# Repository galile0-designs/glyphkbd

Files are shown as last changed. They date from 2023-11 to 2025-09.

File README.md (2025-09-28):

# glyphkbd
**5x13 ortholinear plus TKL nav and arrow clusters**  - Key layout inspired by [drFaustroll's m65](https://mlego.elena.space/m65/) as well as [Stucco](https://www.reddit.com/r/CustomKeyboards/comments/10k8k6w/custom_ortho_tkl_done_stucco1510/).

# v2
glyphkbd_v2 uses a custom PCB with integrated STM32F072 microcontroller using [QMK firmware](https://github.com/qmk/qmk_firmware) [(here)](https://github.com/qmk/qmk_firmware/pull/23131), with [VIA](https://github.com/the-via) use enabled. 3D printed top mount case, [UDB](https://github.com/Unified-Daughterboard/Unified-Daughterboard.github.io) daughterboard for external USB-C connection.

DSC_0071_crop




# License
glyphkbd is licensed under Creative Commons Attribution-NonCommercial-ShareAlike 4.0

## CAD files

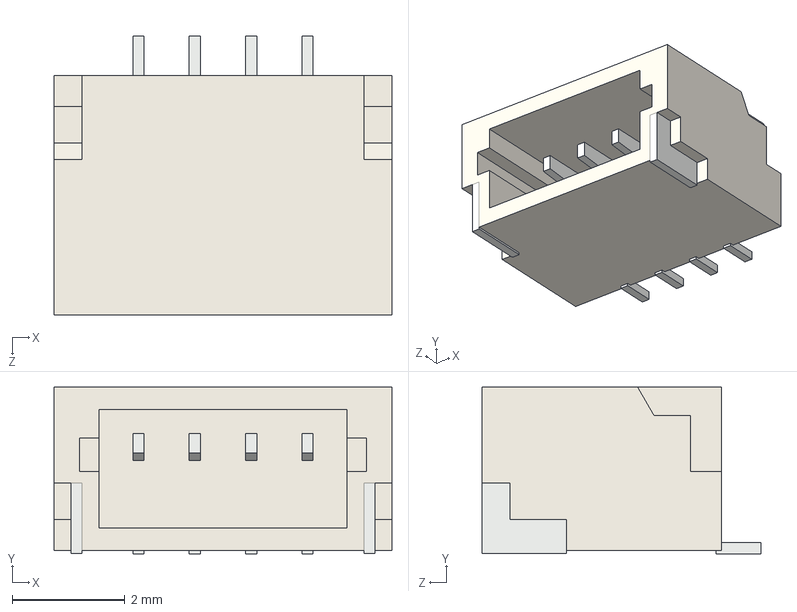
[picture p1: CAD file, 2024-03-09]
v2/PCB/JST SM04B-SRSS-TB.STEP
6.00 x 2.96 x 4.95 mm

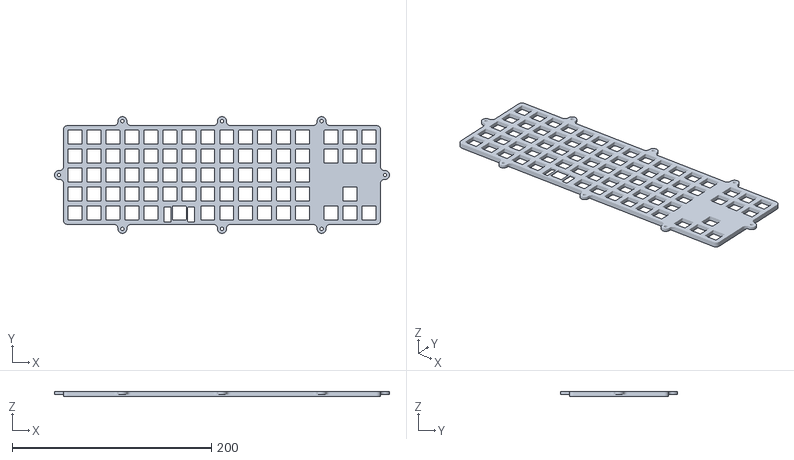
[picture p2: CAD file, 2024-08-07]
v2/printed parts/plate.stl
336.3 x 117.2 x 5.00

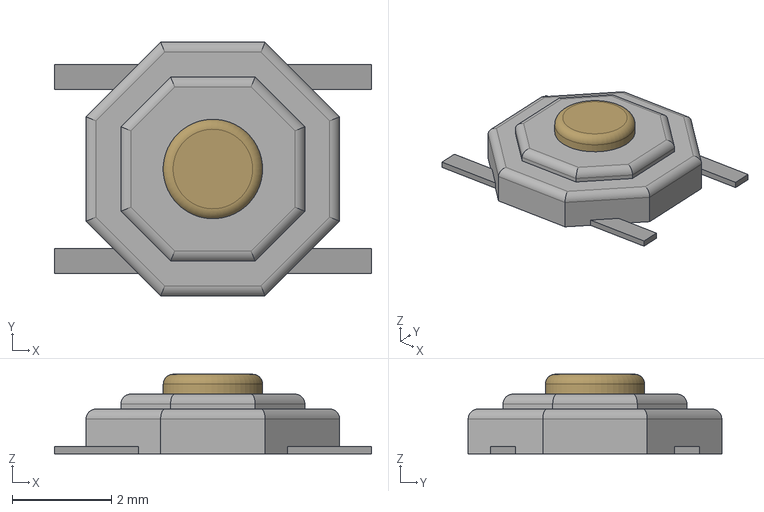
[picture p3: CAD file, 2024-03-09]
v2/PCB/TS-1187A-B-A-B.step
6.38 x 5.10 x 1.60 mm

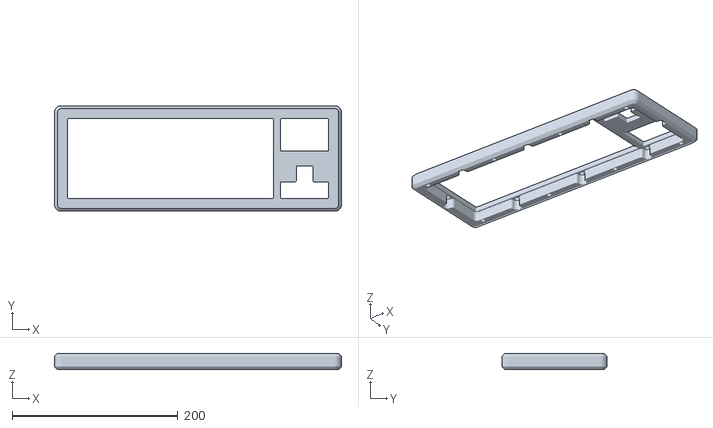
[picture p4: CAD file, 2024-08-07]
v2/printed parts/case.stl
346.3 x 127.2 x 19.5

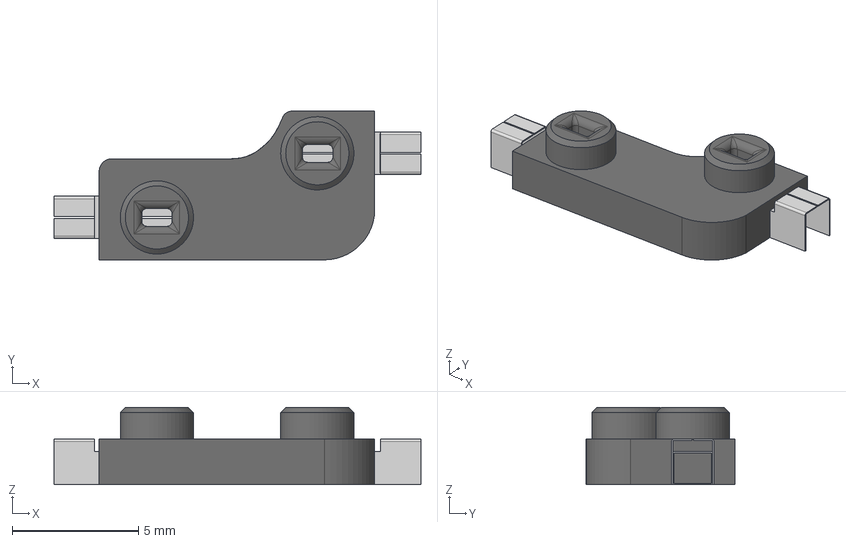
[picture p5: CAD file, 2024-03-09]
v2/PCB/Kailh-CherryMX-Socket.step
14.5 x 5.89 x 3.05 mm

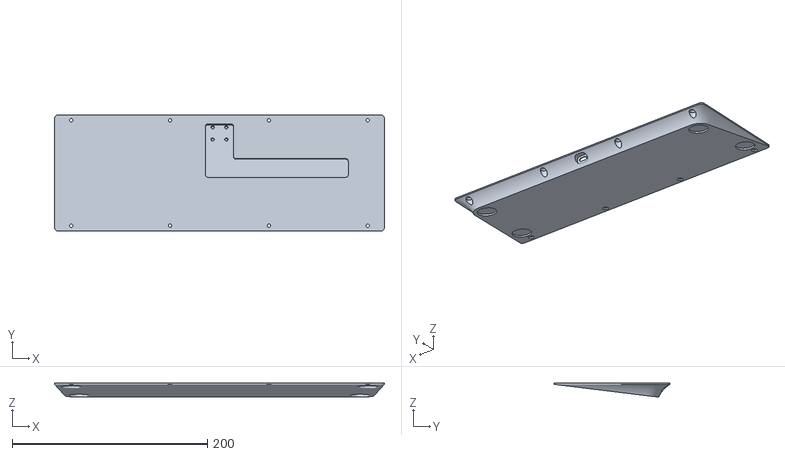
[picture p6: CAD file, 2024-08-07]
v2/printed parts/bottom.stl
338.3 x 119.2 x 14.7

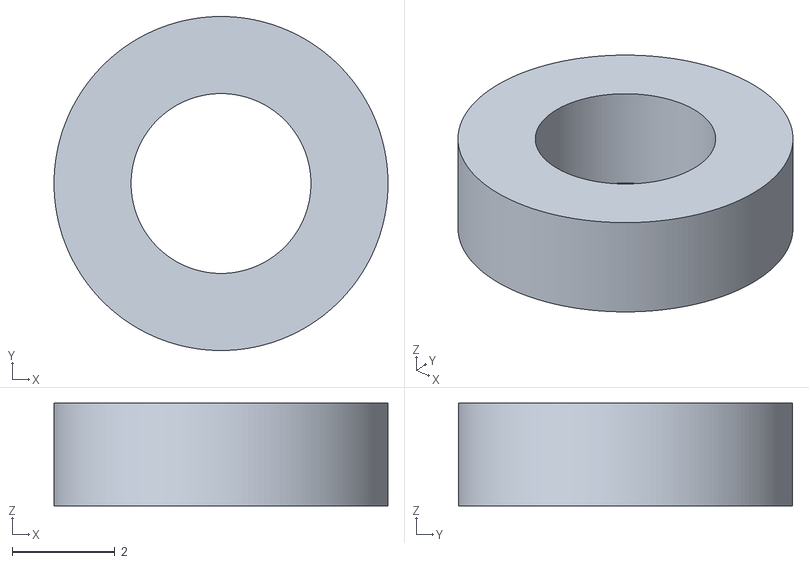
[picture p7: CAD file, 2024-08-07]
v2/printed parts/6x2_topmount_washer.stl
6.50 x 6.50 x 2.00

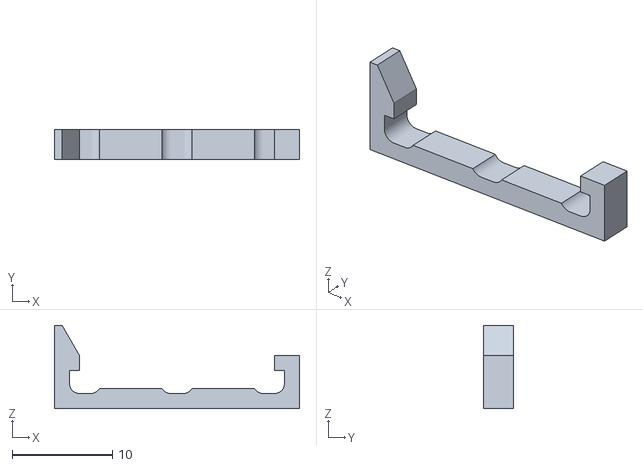
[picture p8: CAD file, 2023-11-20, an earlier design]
v1.2/printed parts/Pico Clip.stl
24.5 x 3.00 x 8.30

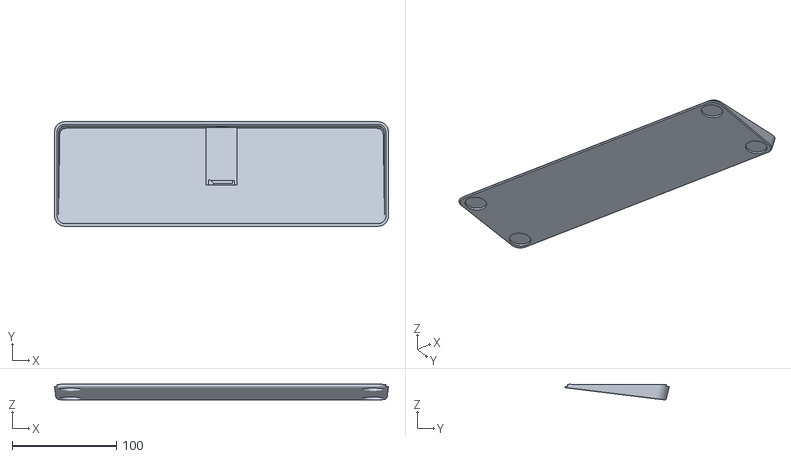
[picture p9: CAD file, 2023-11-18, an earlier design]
v1.2/printed parts/Foot.stl
320.0 x 100.2 x 15.3

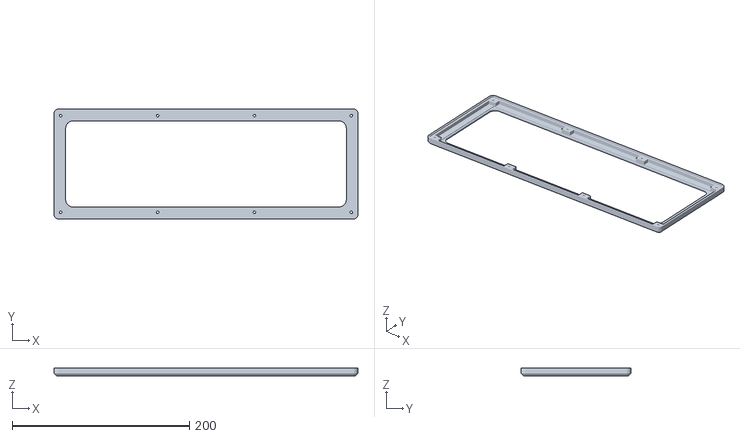
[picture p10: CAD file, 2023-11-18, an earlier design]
v1.2/printed parts/Bottom Case.stl
343.3 x 124.2 x 9.25

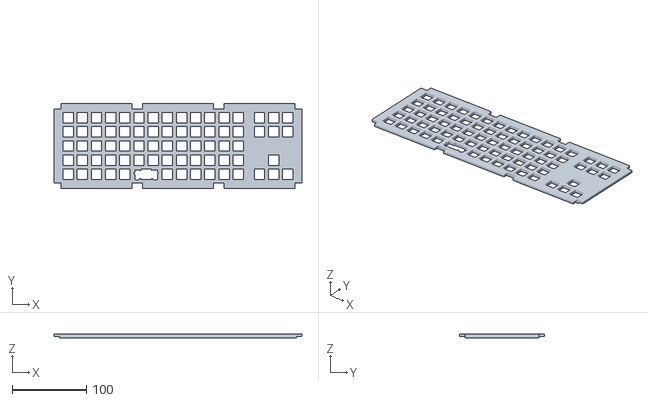
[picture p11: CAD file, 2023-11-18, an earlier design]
v1.2/printed parts/Plate.stl
333.3 x 114.2 x 5.00

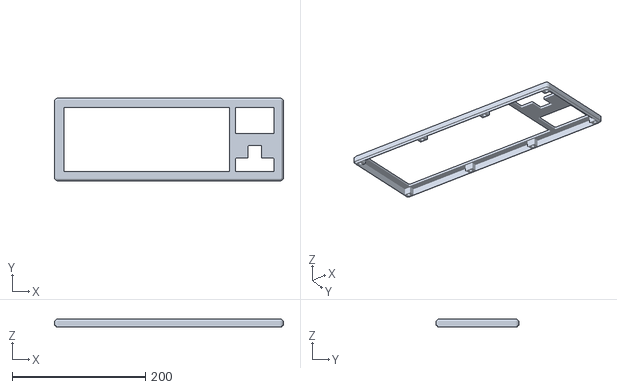
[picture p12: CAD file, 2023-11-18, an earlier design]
v1.2/printed parts/Top Case.stl
343.3 x 124.2 x 11.5

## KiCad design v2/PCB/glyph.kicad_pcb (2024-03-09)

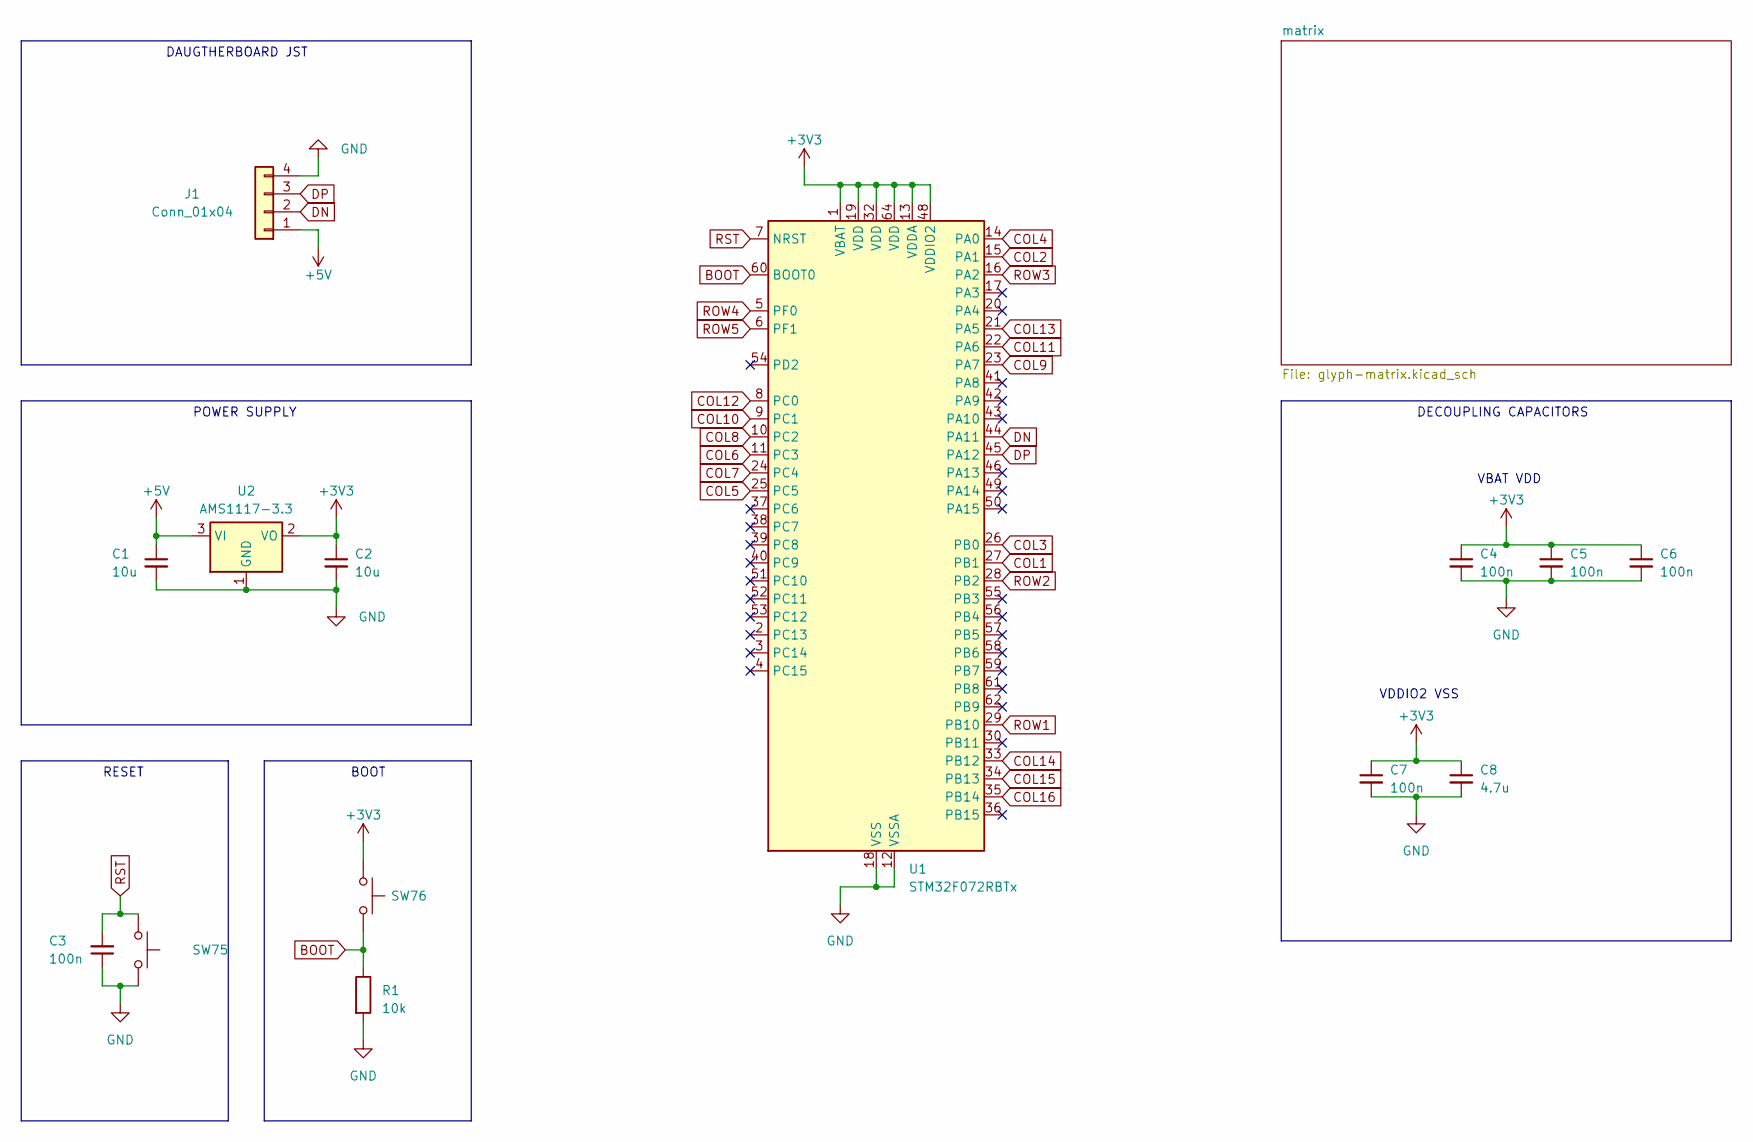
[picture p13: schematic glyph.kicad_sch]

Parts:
C1, C2: 10u; C_0402_1005Metric; LCSC C15525
C3, C4, C5, C6, C7: 100n; C_0402_1005Metric; LCSC C1525
C8: 4.7u; C_0402_1005Metric; LCSC C23733
J1: Conn_01x04; UDB_labeled_JST_SH_SM04B-SRSS-TB_1x04-1MP_P1.00mm_Horizontal; LCSC C160404
R1: 10k; R_0603_1608Metric; LCSC C25804
SW75, SW76: SW_Push; SW_Push_1P1T_XKB_TS-1187A; LCSC C318884
U1: STM32F072RBTx; LQFP-64_10x10mm_P0.5mm; LCSC C46046
U2: AMS1117-3.3; SOT-223-3_TabPin2; LCSC C6186

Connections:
+3V3: C2.1, C4.1, C5.1, C6.1, C7.1, C8.1, SW76.1, U1.1 (VBAT), U1.13 (VDDA), U1.19 (VDD), U1.32 (VDD), U1.48 (VDDIO2), U1.64 (VDD), U2.2 (VO); also elsewhere on the board
+5V: C1.1, J1.1, U2.3 (VI)
BOOT: R1.1, SW76.2, U1.60 (BOOT0); also elsewhere on the board
COL1: U1.27 (PB1); also elsewhere on the board
COL2: U1.15 (PA1); also elsewhere on the board
COL3: U1.26 (PB0); also elsewhere on the board
COL4: U1.14 (PA0); also elsewhere on the board
COL5: U1.25 (PC5); also elsewhere on the board
COL6: U1.11 (PC3); also elsewhere on the board
COL7: U1.24 (PC4); also elsewhere on the board
COL8: U1.10 (PC2); also elsewhere on the board
COL9: U1.23 (PA7); also elsewhere on the board
COL10: U1.9 (PC1); also elsewhere on the board
COL11: U1.22 (PA6); also elsewhere on the board
COL12: U1.8 (PC0); also elsewhere on the board
COL13: U1.21 (PA5); also elsewhere on the board
COL14: U1.33 (PB12); also elsewhere on the board
COL15: U1.34 (PB13); also elsewhere on the board
COL16: U1.35 (PB14); also elsewhere on the board
DN: J1.2, U1.44 (PA11)
DP: J1.3, U1.45 (PA12)
GND: C1.2, C2.2, C3.1, C4.2, C5.2, C6.2, C7.2, C8.2, J1.4, J1.MP, R1.2, SW75.1, U1.12 (VSSA), U1.18 (VSS), U1.31 (VSS), U1.47 (VSS), U1.63 (VSS), U2.1 (GND); also elsewhere on the board
ROW1: U1.29 (PB10); also elsewhere on the board
ROW2: U1.28 (PB2); also elsewhere on the board
ROW3: U1.16 (PA2); also elsewhere on the board
ROW4: U1.5 (PF0); also elsewhere on the board
ROW5: U1.6 (PF1); also elsewhere on the board
RST: C3.2, SW75.2, U1.7 (NRST); also elsewhere on the board

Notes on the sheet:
DAUGTHERBOARD JST
BOOT
VBAT VDD
RESET
DECOUPLING CAPACITORS
POWER SUPPLY
VDDIO2 VSS

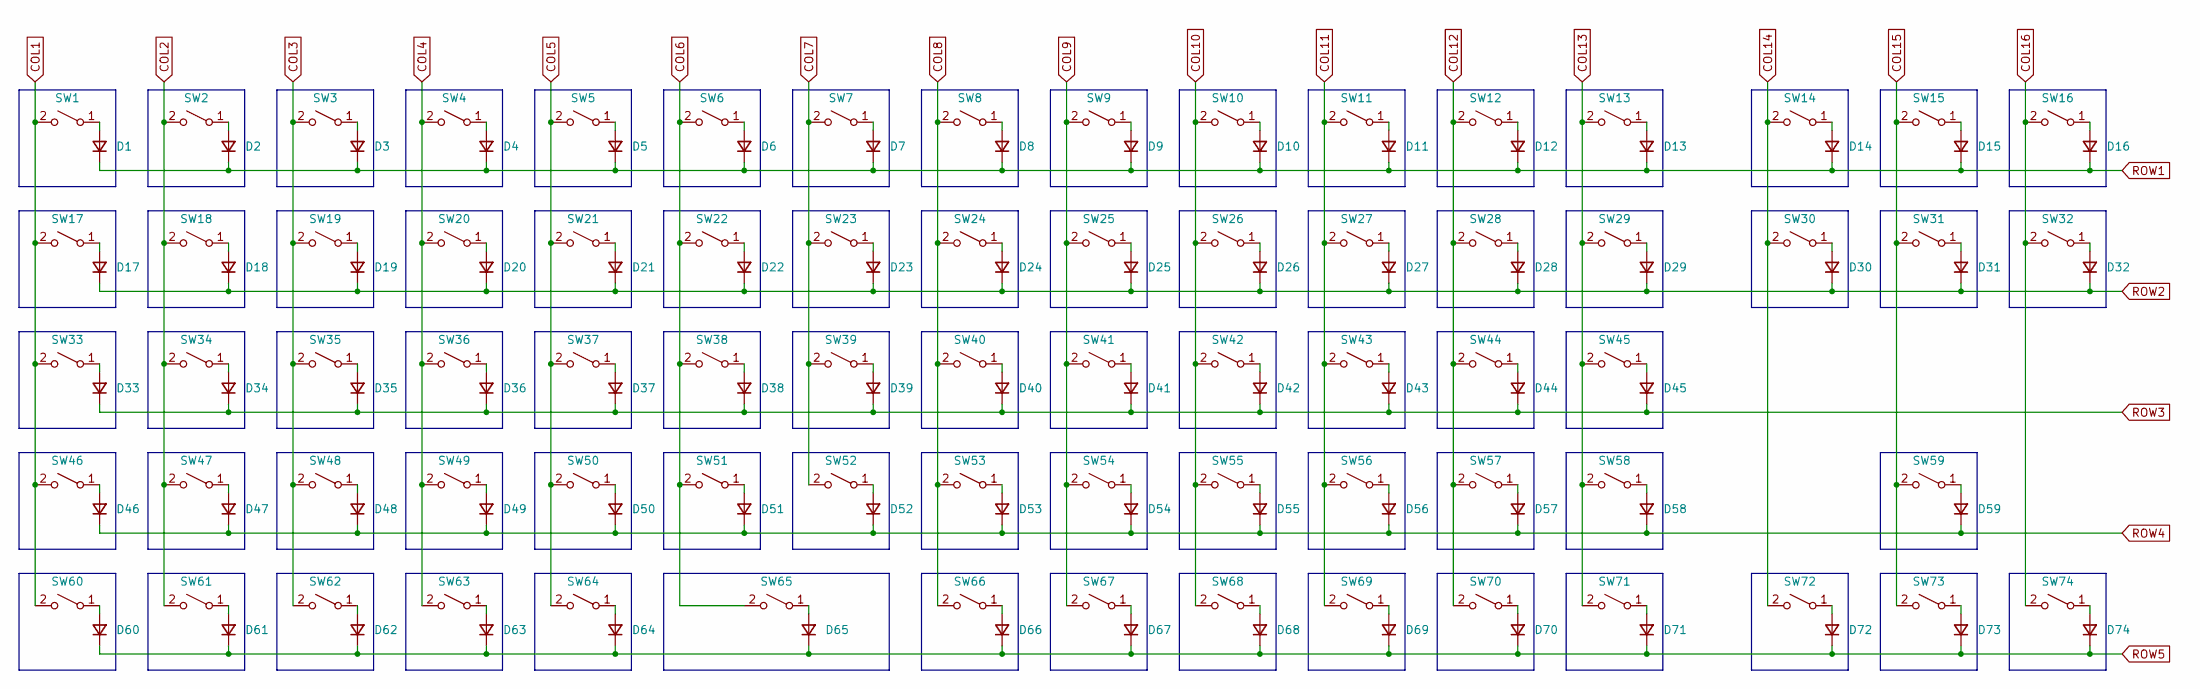
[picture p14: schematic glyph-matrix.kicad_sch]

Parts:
D1, D2, D3, D4, D5, D6, D7, D8, D9, D10, D11, D12, D13, D14, D15, D16, D17, D18, D19, D20, D21, D22, D23, D24, D25, D26, D27, D28, D29, D30, D31, D32, D33, D34, D35, D36, D37, D38, D39, D40, D41, D42, D43, D44, D45, D46, D47, D48, D49, D50, D51, D52, D53, D54, D55, D56, D57, D58, D59, D60, D61, D62, D63, D64, D65, D66, D67, D68, D69, D70, D71, D72, D73, D74: D; D_SOD-123; LCSC C81598
SW1, SW2, SW3, SW4, SW5, SW6, SW7, SW8, SW9, SW10, SW11, SW12, SW13, SW14, SW15, SW16, SW17, SW18, SW19, SW20, SW21, SW22, SW23, SW24, SW25, SW26, SW27, SW28, SW29, SW30, SW31, SW32, SW33, SW34, SW35, SW36, SW37, SW38, SW39, SW40, SW41, SW42, SW43, SW44, SW45, SW46, SW47, SW48, SW49, SW50, SW51, SW52, SW53, SW54, SW55, SW56, SW57, SW58, SW59, SW60, SW61, SW62, SW63, SW64, SW66, SW67, SW68, SW69, SW70, SW71, SW72, SW73, SW74: SW_SPST; CherryMX_Hotswap-Solderable_1u; LCSC C5156480
SW65: SW_SPST; CherryMX_Hotswap-Solderable_2u; LCSC C5156480

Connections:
COL1: SW1.2 (B), SW17.2 (B), SW33.2 (B), SW46.2 (B), SW60.2 (B); also elsewhere on the board
COL2: SW2.2 (B), SW18.2 (B), SW34.2 (B), SW47.2 (B), SW61.2 (B); also elsewhere on the board
COL3: SW3.2 (B), SW19.2 (B), SW35.2 (B), SW48.2 (B), SW62.2 (B); also elsewhere on the board
COL4: SW4.2 (B), SW20.2 (B), SW36.2 (B), SW49.2 (B), SW63.2 (B); also elsewhere on the board
COL5: SW5.2 (B), SW21.2 (B), SW37.2 (B), SW50.2 (B), SW64.2 (B); also elsewhere on the board
COL6: SW6.2 (B), SW22.2 (B), SW38.2 (B), SW51.2 (B), SW65.2 (B); also elsewhere on the board
COL7: SW7.2 (B), SW23.2 (B), SW39.2 (B), SW52.2 (B); also elsewhere on the board
COL8: SW8.2 (B), SW24.2 (B), SW40.2 (B), SW53.2 (B), SW66.2 (B); also elsewhere on the board
COL9: SW9.2 (B), SW25.2 (B), SW41.2 (B), SW54.2 (B), SW67.2 (B); also elsewhere on the board
COL10: SW10.2 (B), SW26.2 (B), SW42.2 (B), SW55.2 (B), SW68.2 (B); also elsewhere on the board
COL11: SW11.2 (B), SW27.2 (B), SW43.2 (B), SW56.2 (B), SW69.2 (B); also elsewhere on the board
COL12: SW12.2 (B), SW28.2 (B), SW44.2 (B), SW57.2 (B), SW70.2 (B); also elsewhere on the board
COL13: SW13.2 (B), SW29.2 (B), SW45.2 (B), SW58.2 (B), SW71.2 (B); also elsewhere on the board
COL14: SW14.2 (B), SW30.2 (B), SW72.2 (B); also elsewhere on the board
COL15: SW15.2 (B), SW31.2 (B), SW59.2 (B), SW73.2 (B); also elsewhere on the board
COL16: SW16.2 (B), SW32.2 (B), SW74.2 (B); also elsewhere on the board
unnamed: D1.2 (A), SW1.1 (A)
unnamed: D2.2 (A), SW2.1 (A)
unnamed: D3.2 (A), SW3.1 (A)
unnamed: D4.2 (A), SW4.1 (A)
unnamed: D5.2 (A), SW5.1 (A)
unnamed: D6.2 (A), SW6.1 (A)
unnamed: D7.2 (A), SW7.1 (A)
unnamed: D8.2 (A), SW8.1 (A)
unnamed: D9.2 (A), SW9.1 (A)
unnamed: D10.2 (A), SW10.1 (A)
unnamed: D11.2 (A), SW11.1 (A)
unnamed: D12.2 (A), SW12.1 (A)
unnamed: D13.2 (A), SW13.1 (A)
unnamed: D14.2 (A), SW14.1 (A)
unnamed: D15.2 (A), SW15.1 (A)
unnamed: D16.2 (A), SW16.1 (A)
unnamed: D17.2 (A), SW17.1 (A)
unnamed: D18.2 (A), SW18.1 (A)
unnamed: D19.2 (A), SW19.1 (A)
unnamed: D20.2 (A), SW20.1 (A)
unnamed: D21.2 (A), SW21.1 (A)
unnamed: D22.2 (A), SW22.1 (A)
unnamed: D23.2 (A), SW23.1 (A)
unnamed: D24.2 (A), SW24.1 (A)
unnamed: D25.2 (A), SW25.1 (A)
unnamed: D26.2 (A), SW26.1 (A)
unnamed: D27.2 (A), SW27.1 (A)
unnamed: D28.2 (A), SW28.1 (A)
unnamed: D29.2 (A), SW29.1 (A)
unnamed: D30.2 (A), SW30.1 (A)
unnamed: D31.2 (A), SW31.1 (A)
unnamed: D32.2 (A), SW32.1 (A)
unnamed: D33.2 (A), SW33.1 (A)
unnamed: D34.2 (A), SW34.1 (A)
unnamed: D35.2 (A), SW35.1 (A)
unnamed: D36.2 (A), SW36.1 (A)
unnamed: D37.2 (A), SW37.1 (A)
unnamed: D38.2 (A), SW38.1 (A)
unnamed: D39.2 (A), SW39.1 (A)
unnamed: D40.2 (A), SW40.1 (A)
unnamed: D41.2 (A), SW41.1 (A)
unnamed: D42.2 (A), SW42.1 (A)
unnamed: D43.2 (A), SW43.1 (A)
unnamed: D44.2 (A), SW44.1 (A)
unnamed: D45.2 (A), SW45.1 (A)
unnamed: D46.2 (A), SW46.1 (A)
unnamed: D47.2 (A), SW47.1 (A)
unnamed: D48.2 (A), SW48.1 (A)
unnamed: D49.2 (A), SW49.1 (A)
unnamed: D50.2 (A), SW50.1 (A)
unnamed: D51.2 (A), SW51.1 (A)
unnamed: D52.2 (A), SW52.1 (A)
unnamed: D53.2 (A), SW53.1 (A)
unnamed: D54.2 (A), SW54.1 (A)
unnamed: D55.2 (A), SW55.1 (A)
unnamed: D56.2 (A), SW56.1 (A)
unnamed: D57.2 (A), SW57.1 (A)
unnamed: D58.2 (A), SW58.1 (A)
unnamed: D59.2 (A), SW59.1 (A)
unnamed: D60.2 (A), SW60.1 (A)
unnamed: D61.2 (A), SW61.1 (A)
unnamed: D62.2 (A), SW62.1 (A)
unnamed: D63.2 (A), SW63.1 (A)
unnamed: D64.2 (A), SW64.1 (A)
unnamed: D65.2 (A), SW65.1 (A)
unnamed: D66.2 (A), SW66.1 (A)
unnamed: D67.2 (A), SW67.1 (A)
unnamed: D68.2 (A), SW68.1 (A)
unnamed: D69.2 (A), SW69.1 (A)
unnamed: D70.2 (A), SW70.1 (A)
unnamed: D71.2 (A), SW71.1 (A)
unnamed: D72.2 (A), SW72.1 (A)
unnamed: D73.2 (A), SW73.1 (A)
unnamed: D74.2 (A), SW74.1 (A)
ROW1: D1.1 (K), D2.1 (K), D3.1 (K), D4.1 (K), D5.1 (K), D6.1 (K), D7.1 (K), D8.1 (K), D9.1 (K), D10.1 (K), D11.1 (K), D12.1 (K), D13.1 (K), D14.1 (K), D15.1 (K), D16.1 (K); also elsewhere on the board
ROW2: D17.1 (K), D18.1 (K), D19.1 (K), D20.1 (K), D21.1 (K), D22.1 (K), D23.1 (K), D24.1 (K), D25.1 (K), D26.1 (K), D27.1 (K), D28.1 (K), D29.1 (K), D30.1 (K), D31.1 (K), D32.1 (K); also elsewhere on the board
ROW3: D33.1 (K), D34.1 (K), D35.1 (K), D36.1 (K), D37.1 (K), D38.1 (K), D39.1 (K), D40.1 (K), D41.1 (K), D42.1 (K), D43.1 (K), D44.1 (K), D45.1 (K); also elsewhere on the board
ROW4: D46.1 (K), D47.1 (K), D48.1 (K), D49.1 (K), D50.1 (K), D51.1 (K), D52.1 (K), D53.1 (K), D54.1 (K), D55.1 (K), D56.1 (K), D57.1 (K), D58.1 (K), D59.1 (K); also elsewhere on the board
ROW5: D60.1 (K), D61.1 (K), D62.1 (K), D63.1 (K), D64.1 (K), D65.1 (K), D66.1 (K), D67.1 (K), D68.1 (K), D69.1 (K), D70.1 (K), D71.1 (K), D72.1 (K), D73.1 (K), D74.1 (K); also elsewhere on the board

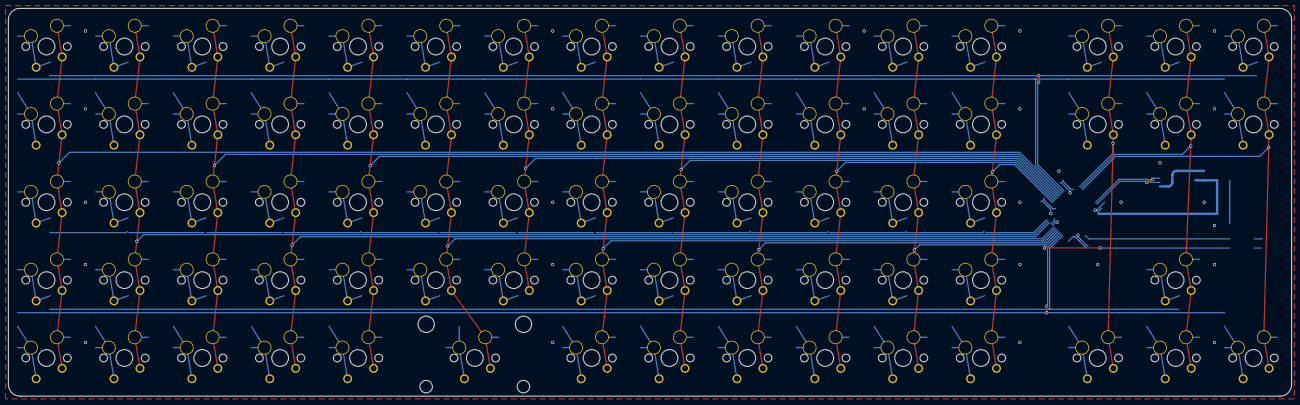
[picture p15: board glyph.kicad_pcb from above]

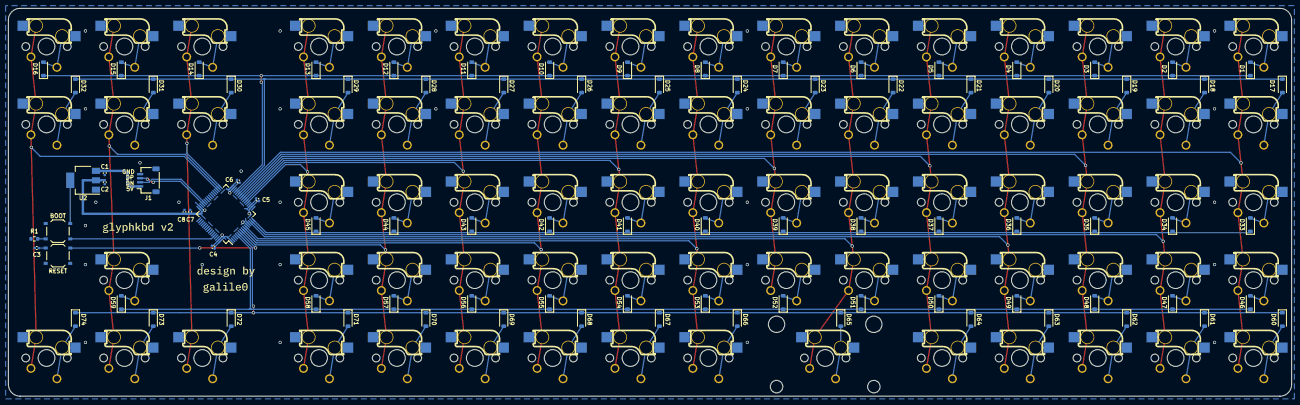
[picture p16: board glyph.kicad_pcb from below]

Board: 2 copper layers, 313.9 x 94.9 mm, 162 parts (162 on the bottom side), 102 nets.

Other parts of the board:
BOOT: SW_Push; SW_Push_1P1T_XKB_TS-1187A
RESET: SW_Push; SW_Push_1P1T_XKB_TS-1187A

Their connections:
+3V3: BOOT.1; also elsewhere on the board
BOOT: BOOT.2; also elsewhere on the board
GND: RESET.1; also elsewhere on the board
RST: RESET.2; also elsewhere on the board

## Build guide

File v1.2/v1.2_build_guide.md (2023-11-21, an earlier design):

# v1.2 build guide
This page will walk you through the complete process of assembling a glyph v1.2.
Let's start with everything you'll need:

- printed parts: bottom and top case, foot, pico clip, plate
- 3D pen is recommended (soldering iron can also work but is more messy)
- 8x M2,5 threaded inserts, 5mm length, 3,5-4mm OD, [example](https://www.aliexpress.com/item/1005004870993068.html)
- 8x M2,5x12mm countersunk screws, DIN7991 or similar. M2,5x16 will also fit
- rubber feet, ⌀20x3mm, [example](https://www.aliexpress.com/item/1005004003601545.html)
- RasPi Pico clone with USB-C, [example](https://www.aliexpress.com/item/1005003928558306.html) (authentic pico will not fit, has different dimensions)
- 9mm P-profile self-adhesive rubber sealing strips, [example](https://www.amazon.se/-/en/RUBBER-IDITATION-Profile-Adhesive-Sealing/dp/B00SM048D0)
- 74 MX-style switches
- 1x 2u plate mount MX-style stabilizer
- basic handwiring supplies: axial signal diodes e.g 1N4148, insulated wire, soldering equipment
- optional but useful: loose hotswap sockets, rainbow ribbon cable

# Printed parts:
parts

All of the case parts are printed in PLA and the plate is printed in PETG. Everything is printed with solid infill, to increase mass and improve sound.

# Case
The controller of v1 glyph, the pico clone, is held in place on inside of the foot by a small 3d printed clip. In order for this clip to be durable, it has to be printed in the flat orientation, separately. Let's attach it to the foot now:

clip_welded

Align the center divit of the clip with the USB C hole on the foot, and weld it into place with your 3D pen (or soldering iron, if you must). The Pico should snap in pretty easily and sit snugly. You should be able to release it by putting some pressure on the lever.

One of the unique design choices that I made with this keyboard design was to split the bottom case from the foot. This means that we can use this more interesting and proper-looking foot design, we have a nice smooth surface on both the bottom case and the bottom of the foot, and we avoid all of the annoying support material we would otherwise need. This is in my opinion more than worth the small trade-off of having to weld them together on the inside. If done right, it looks completely seamless from the outside.

foot_welded

Use the 3D pen with some loose filament kind of like a MIG welder, extruding molten plastic into the gap. Before you begin, it's best to make sure that the foot and case are aligned properly with an even gap all the way around. When welding, it's best to go slowly and sort of massage the plastic into both sides of the seam, you don't want a cold weld.

The glyph v1.2 screws together from bottom to top with some threaded inserts in the top case. Add these inserts now. Simply use a soldering iron to heat up and press your threaded inserts into the holes on the inside of the top case. Depending on the outer diameter of the ones you've picked, it may be necessary to drill the holes in the top case to a larger size.

Add the rubber feet to the bottom

feet_adhered

# Wiring 
First, pop all of your switches and your stabilizer into the plate. If you printed the plate with your nozzle a little too close to the bed, you may have to file away the little lip that forms around the circumference of the switch holes before you can pop them in. I've tried enlarging the holes to compensate for this effect, but even 0,1mm leads to switches popping out way too easily. Such is the curse of 3D printed plates... Same applies for the stabilizer. 

switches_in

Next, I like to add hotswap sockets so that I don't have to solder directly onto the switch legs of my precious black inks. This is optional though, if you dont care about them, you can just solder directly onto your switches.

sockets_on

The next step is to solder the diodes, and solder them into rows.

rows_completed

Then the columns. I like to use some rainbow ribbon cable here, it looks dope and helps me keep track of the order when soldering to the controller.

columns_completed

Now add the sealing strips to the plate. Ideally they should overhang about 0,5-1mm over the edges to help with alignment relative to the case.

strips_adhered

Now to wire the matrix up to the Pico. The standard pinout is as follows, but you can change this easily by just editing the pin configuraton in the main.py firmware file.

glyph_v1 2_pinout

pico_wiring

yes, spagetti

# Firmware
glyph v1 runs KMK firmware, which makes this really just a drag and drop procedure, no special software required!

First, hold down the bootloader button on your pico while pluging it into USB. It should enter bootloader mode and appear on your system as a flash drive. Now download CircuitPython from [here](https://circuitpython.org/board/raspberry_pi_pico/) and drag the .uf2 file into the pico flash drive. It will now automatically reboot, and appear as a new empty flash drive now named CIRCUITPY. This drive should contain a file called code.py by default, delete this file.

Now download the KMK firmware repository from [here](https://github.com/KMKfw/kmk_firmware), and drag and drop the "kmk" folder to the CIRCUITPY drive. Now drag and drop the "main.py" and "boot.py" firmware files for glyph v1.2 to CIRCUITPY. Disconnect the keyboard and plug it in again. Your glyph should now be working.

**IMPORTANT! By default, the boot.py file sets the controller to not show up as a flash drive anymore, in order to avoid annoying file manager pop ups when plugging in. If you want access to the drive later, like for modifying the firmware, simply hold down ESC while plugging the board in. This will override boot.py, causing it to show up as a drive until rebooted.**

finished

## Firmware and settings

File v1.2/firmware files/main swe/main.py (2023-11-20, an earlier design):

# glyph v1 kmk firmware main, swedish edition :)

import board

from kmk.kmk_keyboard import KMKKeyboard
from kmk.keys import KC
from kmk.scanners import DiodeOrientation
from kmk.modules.layers import Layers
from kmk.extensions.media_keys import MediaKeys

keyboard = KMKKeyboard()

keyboard.col_pins = (
    board.GP1,
    board.GP2,
    board.GP3,
    board.GP4,
    board.GP5,
    board.GP6,
    board.GP7,
    board.GP8,
    board.GP20,
    board.GP21,
    board.GP22,
    board.GP23,
    board.GP24,
    board.GP25,
    board.GP26,
    board.GP27,
)

keyboard.row_pins = (
    board.GP11,
    board.GP12,
    board.GP13,
    board.GP14,
    board.GP15,
)

keyboard.diode_orientation = DiodeOrientation.COL2ROW
keyboard.modules.append(Layers())
keyboard.extensions.append(MediaKeys())


Å = KC.RALT(KC.W)
Ö = KC.RALT(KC.P)   
Ä = KC.RALT(KC.Q)

keyboard.keymap = [

	# base layer
    [
	##########-##########-##########-##########-##########-##########-##########-##########-##########-##########-##########-##########-##########-##########-##########-##########
        KC.ESC,    KC.N1,     KC.N2,     KC.N3,     KC.N4,     KC.N5,     KC.N6,     KC.N7,     KC.N8,     KC.N9,     KC.N0,     KC.MINS,   KC.BSPC,   KC.INS,    KC.HOME,   KC.PGUP, 
	KC.TAB,    KC.Q,      KC.W,      KC.E,      KC.R,      KC.T,      KC.Y,      KC.U,      KC.I,      KC.O,      KC.P,      KC.LBRC,   KC.RBRC,   KC.DEL,    KC.END,    KC.PGDN, 
	KC.CAPS,   KC.A,      KC.S,      KC.D,      KC.F,      KC.G,      KC.H,      KC.J,      KC.K,      KC.L,      KC.SCLN,   KC.QUOT,   KC.ENT,    KC.NO,     KC.NO,     KC.NO,   
	KC.LSFT,   KC.BSLS,   KC.Z,      KC.X,      KC.C,      KC.V,      KC.B,      KC.N,      KC.M,      KC.COMM,   KC.DOT,    KC.SLSH,   KC.RSFT,   KC.NO,     KC.UP,     KC.NO,   
	KC.LCTL,   KC.NO,     KC.LGUI,   KC.LALT,   KC.MO(1),  KC.SPC,    KC.NO,     KC.SPC,    KC.MO(3),  KC.RALT,   KC.RGUI,   KC.MO(2),  KC.RCTL,   KC.LEFT,   KC.DOWN,   KC.RGHT, 

    ],

	# function layer
    [
	##########-##########-##########-##########-##########-##########-##########-##########-##########-##########-##########-##########-##########-##########-##########-##########
        KC.NO,     KC.F1,     KC.F2,     KC.F3,     KC.F4,     KC.F5,     KC.F6,     KC.F7,     KC.F8,     KC.F9,     KC.F10,    KC.F11,    KC.F12,    KC.PSCR,   KC.SLCK,   KC.BRK,     
	KC.NO,     KC.NO,     KC.NO,     KC.NO,     KC.NO,     KC.NO,     KC.NO,     KC.NO,     KC.NO,     KC.NO,     KC.NO,     KC.NO,     KC.NO,     KC.NO,     KC.NO,     KC.NO,     
	KC.NO,     KC.NO,     KC.NO,     KC.NO,     KC.NO,     KC.NO,     KC.NO,     KC.NO,     KC.NO,     KC.NO,     KC.NO,     KC.NO,     KC.NO,     KC.NO,     KC.NO,     KC.NO,     
	KC.NO,     KC.NO,     KC.NO,     KC.NO,     KC.NO,     KC.NO,     KC.NO,     KC.NO,     KC.NO,     KC.NO,     KC.NO,     KC.NO,     KC.NO,     KC.NO,     KC.NO,     KC.NO,     
	KC.NO,     KC.NO,     KC.NO,     KC.NO,     KC.TRNS,   KC.NO,     KC.NO,     KC.NO,     KC.TRNS,   KC.NO,     KC.NO,     KC.TRNS,   KC.NO,     KC.NO,     KC.NO,     KC.NO,     

    ],

	# media layer
    [
	##########-##########-##########-##########-##########-##########-##########-##########-##########-##########-##########-##########-##########-##########-##########-##########
	KC.NO,     KC.NO,     KC.NO,     KC.NO,     KC.NO,     KC.NO,     KC.NO,     KC.NO,     KC.NO,     KC.NO,     KC.NO,     KC.NO,     KC.NO,     KC.NO,     KC.NO,     KC.VOLU,     
	KC.NO,     KC.NO,     KC.NO,     KC.NO,     KC.NO,     KC.NO,     KC.NO,     KC.NO,     KC.NO,     KC.NO,     KC.NO,     KC.NO,     KC.NO,     KC.MPLY,   KC.NO,     KC.VOLD,     
	KC.NO,     KC.NO,     KC.NO,     KC.NO,     KC.NO,     KC.NO,     KC.NO,     KC.NO,     KC.NO,     KC.NO,     KC.NO,     KC.NO,     KC.NO,     KC.NO,     KC.NO,     KC.NO,     
	KC.NO,     KC.NO,     KC.NO,     KC.NO,     KC.NO,     KC.NO,     KC.NO,     KC.NO,     KC.NO,     KC.NO,     KC.NO,     KC.NO,     KC.NO,     KC.NO,     KC.NO,     KC.NO,     
	KC.NO,     KC.NO,     KC.NO,     KC.NO,     KC.TRNS,   KC.NO,     KC.NO,     KC.NO,     KC.TRNS,   KC.NO,     KC.NO,     KC.TRNS,   KC.NO,     KC.NO,     KC.NO,     KC.NO,     

    ],

	# symbol layer
    [
	##########-##########-##########-##########-##########-##########-##########-##########-##########-##########-##########-##########-##########-##########-##########-##########
        KC.GRV,    KC.NO,     KC.NO,     KC.NO,     KC.NO,     KC.NO,     KC.NO,     KC.NO,     KC.NO,     KC.NO,     KC.EQL,    KC.PPLS,   KC.NO,     KC.NO,     KC.NO,     KC.NO,     
        KC.NO,     KC.NO,     KC.NO,     KC.NO,     KC.NO,     KC.NO,     KC.NO,     KC.NO,     KC.NO,     KC.NO,     KC.NO,     Å,         KC.NO,     KC.NO,     KC.NO,     KC.NO,     
	KC.NO,     KC.NO,     KC.NO,     KC.NO,     KC.NO,     KC.NO,     KC.NO,     KC.NO,     KC.NO,     KC.NO,     Ö,         Ä,         KC.NO,     KC.NO,     KC.NO,     KC.NO,   
	KC.LSFT,   KC.NO,     KC.NO,     KC.NO,     KC.NO,     KC.NO,     KC.NO,     KC.NO,     KC.NO,     KC.NO,     KC.NO,     KC.NO,     KC.RSFT,   KC.NO,     KC.NO,     KC.NO,     
	KC.NO,     KC.NO,     KC.NO,     KC.NO,     KC.TRNS,   KC.NO,     KC.NO,     KC.NO,     KC.TRNS,   KC.NO,     KC.NO,     KC.TRNS,   KC.NO,     KC.NO,     KC.NO,     KC.NO,     

    ],

]

if __name__ == "__main__":
    keyboard.go()

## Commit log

2023-11-18 v1.2 upload
    [Bottom Case.stl, Foot.stl, Plate.stl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]
2024-03-09 added v2 pcb files
    [JST SM04B-SRSS-TB.STEP, Kailh-CherryMX-Socket.step, TS-1187A-B-A-B.step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]
2024-08-07 publish case and plate files
    [6x2_topmount_washer.stl, bottom.stl, case.stl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]
